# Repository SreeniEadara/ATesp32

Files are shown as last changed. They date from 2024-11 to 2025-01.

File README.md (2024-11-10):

# ATesp32

This is an ATmega32A replacement that uses the ESP32-S3.
Why? Because I bought ATmega32-based keyboard PCBs (the Discipline), love it and want to add wireless capabilities (BLE) and native USB.

I've made efforts to maintain the same number of GPIO, but there will be many differences you would encounter if trying to use this as an ATmega32A replacement. These would include logic levels, availability of analog pins, clock, etc.

Thank you to Adafruit for making the Feather and QtPy boards for the ESP32-S3!
I heavily referenced these in this design.
https://github.com/adafruit/Adafruit-Feather-ESP32-S3-PCB
https://github.com/adafruit/Adafruit-QT-Py-ESP32-S3-PCB/tree/main

Call me an Adafruit shill if you will, but you can support open hardware by purchasing from them.

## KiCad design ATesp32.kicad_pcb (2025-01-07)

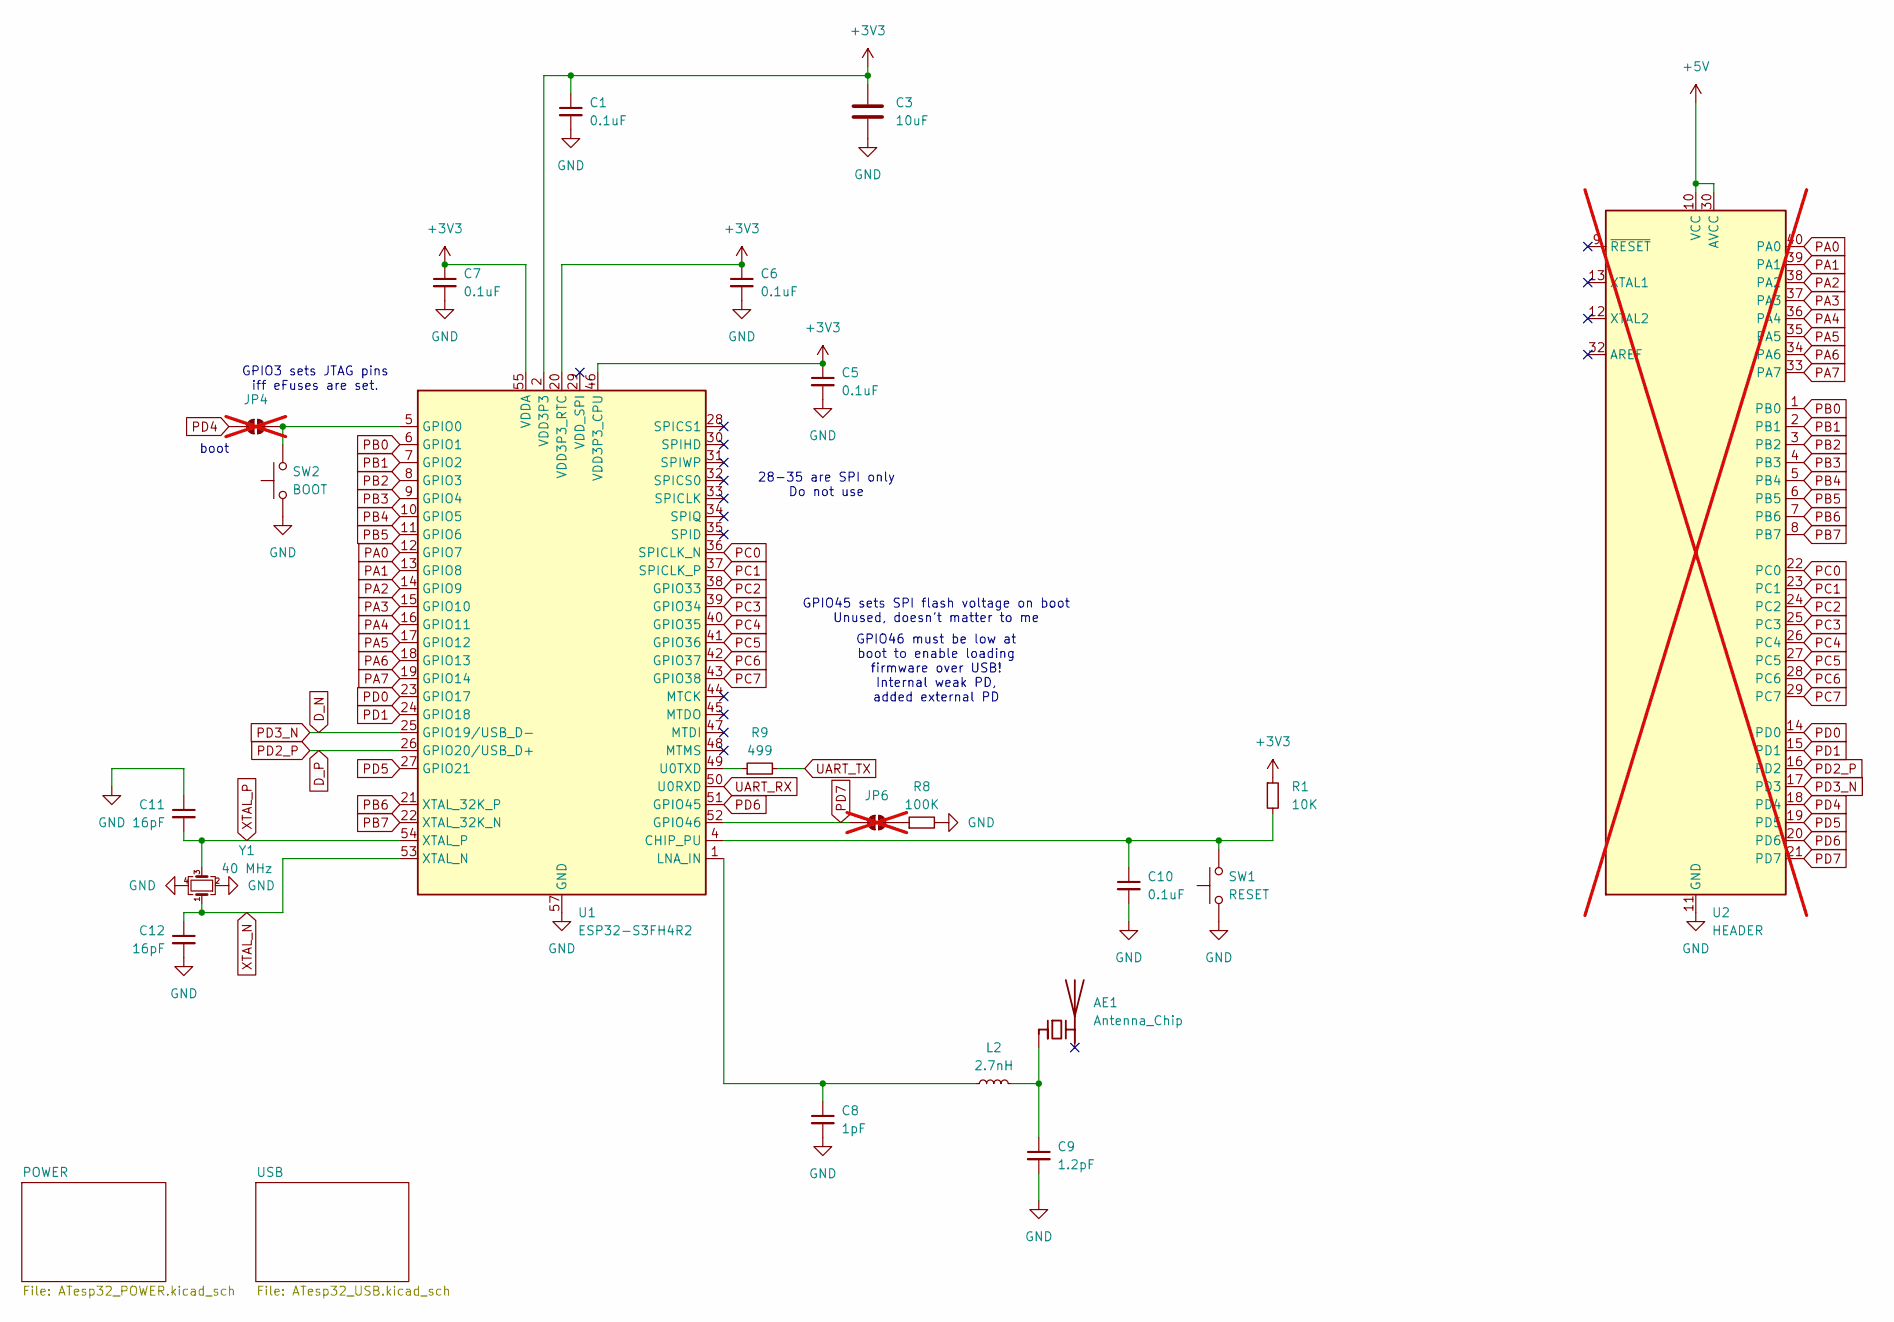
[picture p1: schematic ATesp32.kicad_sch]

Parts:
AE1: Antenna_Chip; Johanson_2450AT18x100; DigiKey 712-2450AT18B0100001ECT-ND
C1, C5, C6, C7, C10: 0.1uF; C_0402_1005Metric; LCSC C1525
C3: 10uF; C_0402_1005Metric; LCSC C315248
C8: 1pF; C_0402_1005Metric; DigiKey 1276-6609-1-ND
C9: 1.2pF; C_0402_1005Metric; DigiKey 1276-1654-1-ND
C11, C12: 16pF; C_0402_1005Metric; LCSC C541434
JP4, JP6: SolderJumper_2_Open; SolderJumper-2_P1.3mm_Open_RoundedPad1.0x1.5mm; not fitted
L2: 2.7nH; L_0402_1005Metric; LCSC C434826
R1: 10K; R_0402_1005Metric; LCSC C25744
R8: 100K; R_0402_1005Metric; LCSC C25741
R9: 499; R_0402_1005Metric; LCSC C4125
SW1: RESET; SW_Push_1P1T_NO_CK_KMR2; LCSC C221680
SW2: BOOT; SW_Push_1P1T_NO_CK_KMR2; LCSC C221680
U1: ESP32-S3FH4R2; QFN-56-1EP_7x7mm_P0.4mm_EP4x4mm; Mouser 356-ESP32-S3FH4R2
U2: HEADER; DIP-40_W15.24mm; not fitted
Y1: 40 MHz; Crystal_SMD_Abracon_ABM8G-4Pin_3.2x2.5mm; DigiKey 535-14086-1-ND

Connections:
+3V3: C1.1, C3.1, C5.1, C6.1, C7.1, R1.1, U1.2 (VDD3P3), U1.3 (VDD3P3), U1.20 (VDD3P3_RTC), U1.46 (VDD3P3_CPU), U1.55 (VDDA), U1.56 (VDDA); also elsewhere on the board
+5V: U2.10 (VCC), U2.30 (AVCC); also elsewhere on the board
D_N: U1.25 (GPIO19/USB_D-), U2.17 (PD3)
D_P: U1.26 (GPIO20/USB_D+), U2.16 (PD2)
GND: C1.2, C3.2, C5.2, C6.2, C7.2, C8.2, C9.2, C10.2, C11.1, C12.2, R8.2, SW1.1, SW2.1, U1.57 (GND), U2.11 (GND), U2.31 (GND), Y1.2, Y1.4; also elsewhere on the board
unnamed: AE1.1 (FEED), C9.1, L2.2
unnamed: JP4.2 (B), SW2.2, U1.5 (GPIO0)
unnamed: JP6.2 (B), R8.1
unnamed: C10.1, R1.2, SW1.2, U1.4 (CHIP_PU)
unnamed: C8.1, L2.1, U1.1 (LNA_IN)
unnamed: R9.1, U1.49 (U0TXD)
PA0: U1.12 (GPIO7), U2.40 (PA0)
PA1: U1.13 (GPIO8), U2.39 (PA1)
PA2: U1.14 (GPIO9), U2.38 (PA2)
PA3: U1.15 (GPIO10), U2.37 (PA3)
PA4: U1.16 (GPIO11), U2.36 (PA4)
PA5: U1.17 (GPIO12), U2.35 (PA5)
PA6: U1.18 (GPIO13), U2.34 (PA6)
PA7: U1.19 (GPIO14), U2.33 (PA7)
PB0: U1.6 (GPIO1), U2.1 (PB0)
PB1: U1.7 (GPIO2), U2.2 (PB1)
PB2: U1.8 (GPIO3), U2.3 (PB2)
PB3: U1.9 (GPIO4), U2.4 (PB3)
PB4: U1.10 (GPIO5), U2.5 (PB4)
PB5: U1.11 (GPIO6), U2.6 (PB5)
PB6: U1.21 (XTAL_32K_P), U2.7 (PB6)
PB7: U1.22 (XTAL_32K_N), U2.8 (PB7)
PC0: U1.36 (SPICLK_N), U2.22 (PC0)
PC1: U1.37 (SPICLK_P), U2.23 (PC1)
PC2: U1.38 (GPIO33), U2.24 (PC2)
PC3: U1.39 (GPIO34), U2.25 (PC3)
PC4: U1.40 (GPIO35), U2.26 (PC4)
PC5: U1.41 (GPIO36), U2.27 (PC5)
PC6: U1.42 (GPIO37), U2.28 (PC6)
PC7: U1.43 (GPIO38), U2.29 (PC7)
PD0: U1.23 (GPIO17), U2.14 (PD0)
PD1: U1.24 (GPIO18), U2.15 (PD1)
PD4: JP4.1 (A), U2.18 (PD4)
PD5: U1.27 (GPIO21), U2.19 (PD5)
PD6: U1.51 (GPIO45), U2.20 (PD6)
PD7: JP6.1 (A), U1.52 (GPIO46), U2.21 (PD7)
UART_RX: U1.50 (U0RXD); also elsewhere on the board
UART_TX: R9.2; also elsewhere on the board
XTAL_N: C12.1, U1.53 (XTAL_N), Y1.1
XTAL_P: C11.2, U1.54 (XTAL_P), Y1.3

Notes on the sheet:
GPIO45 sets SPI flash voltage on boot Unused, doesn't matter to me
boot
28-35 are SPI only Do not use
GPIO3 sets JTAG pins iff eFuses are set.
GPIO46 must be low at boot to enable loading firmware over USB! Internal weak PD, added external PD

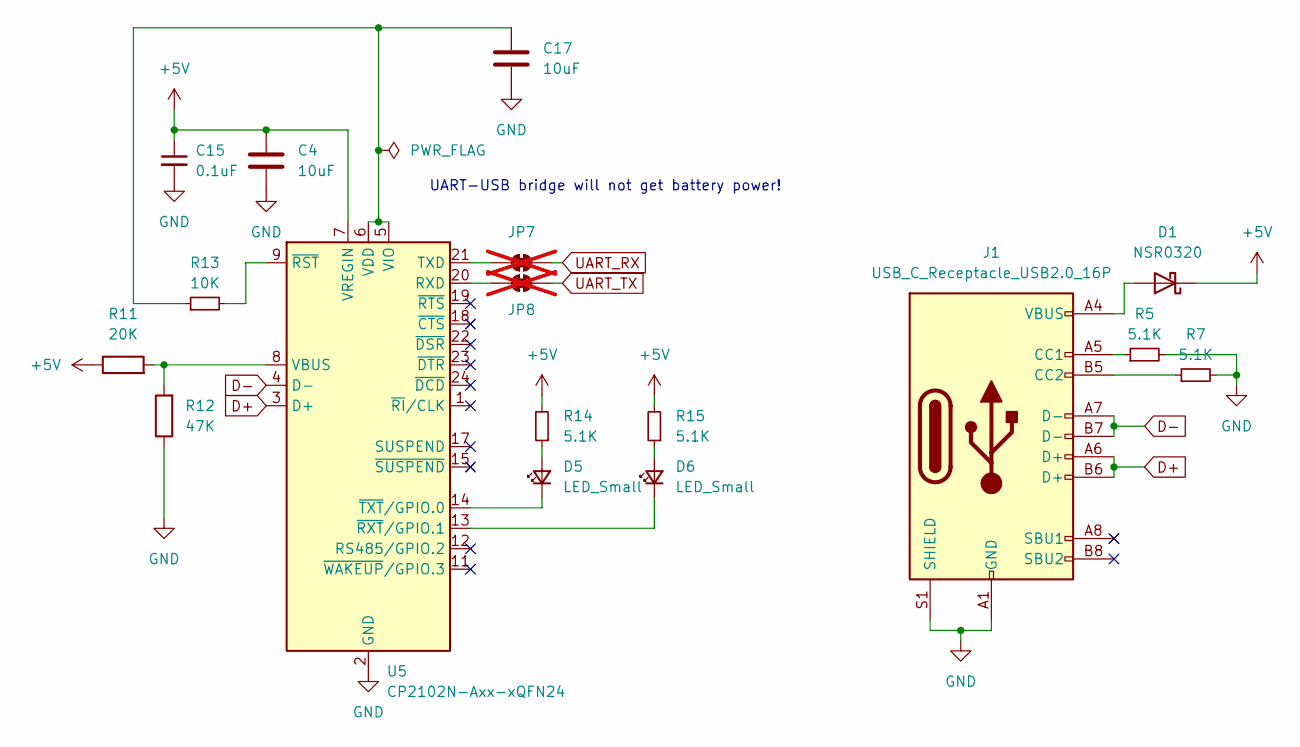
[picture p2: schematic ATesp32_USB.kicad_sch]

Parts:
C4, C17: 10uF; C_0402_1005Metric; LCSC C315248
C15: 0.1uF; C_0402_1005Metric; LCSC C1525
D1: NSR0320; D_SOD-323; LCSC C48192
D5, D6: LED_Small; LED_0402_1005Metric; LCSC C510300
J1: USB_C_Receptacle_USB2.0_16P; USB_C_Receptacle_GCT_USB4105-xx-A_16P_TopMnt_Horizontal; LCSC C2988369
JP7, JP8: SolderJumper_2_Bridged; SolderJumper-2_P1.3mm_Bridged_RoundedPad1.0x1.5mm; not fitted
R5, R7, R14, R15: 5.1K; R_0402_1005Metric; LCSC C25905
R11: 20K; R_0402_1005Metric; LCSC C25765
R12: 47K; R_0402_1005Metric; LCSC C25792
R13: 10K; R_0402_1005Metric; LCSC C25744
U5: CP2102N-Axx-xQFN24; QFN-24-1EP_4x4mm_P0.5mm_EP2.6x2.6mm; LCSC C969151

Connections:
+5V: C4.1, C15.1, D1.1 (K), R11.1, R14.2, R15.2, U5.7 (VREGIN); also elsewhere on the board
D+: J1.A6 (D+), J1.B6 (D+), U5.3 (D+)
D-: J1.A7 (D-), J1.B7 (D-), U5.4 (D-)
GND: C4.2, C15.2, C17.2, J1.A1 (GND), J1.A12 (GND), J1.B1 (GND), J1.B12 (GND), J1.S1 (SHIELD), R5.2, R7.2, R12.1, U5.2 (GND), U5.25 (GND); also elsewhere on the board
unnamed: D1.2 (A), J1.A4 (VBUS), J1.A9 (VBUS), J1.B4 (VBUS), J1.B9 (VBUS)
unnamed: D5.2 (A), R14.1
unnamed: D5.1 (K), U5.14 (~TXT/GPIO.0)
unnamed: D6.2 (A), R15.1
unnamed: D6.1 (K), U5.13 (~RXT/GPIO.1)
unnamed: J1.A5 (CC1), R5.1
unnamed: J1.B5 (CC2), R7.1
unnamed: JP7.1 (A), U5.21 (TXD)
unnamed: JP8.1 (A), U5.20 (RXD)
unnamed: R11.2, R12.2, U5.8 (VBUS)
unnamed: C17.1, R13.1, U5.5 (VIO), U5.6 (VDD)
unnamed: R13.2, U5.9 (~RST)
UART_RX: JP7.2 (B); also elsewhere on the board
UART_TX: JP8.2 (B); also elsewhere on the board

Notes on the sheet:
UART-USB bridge will not get battery power!

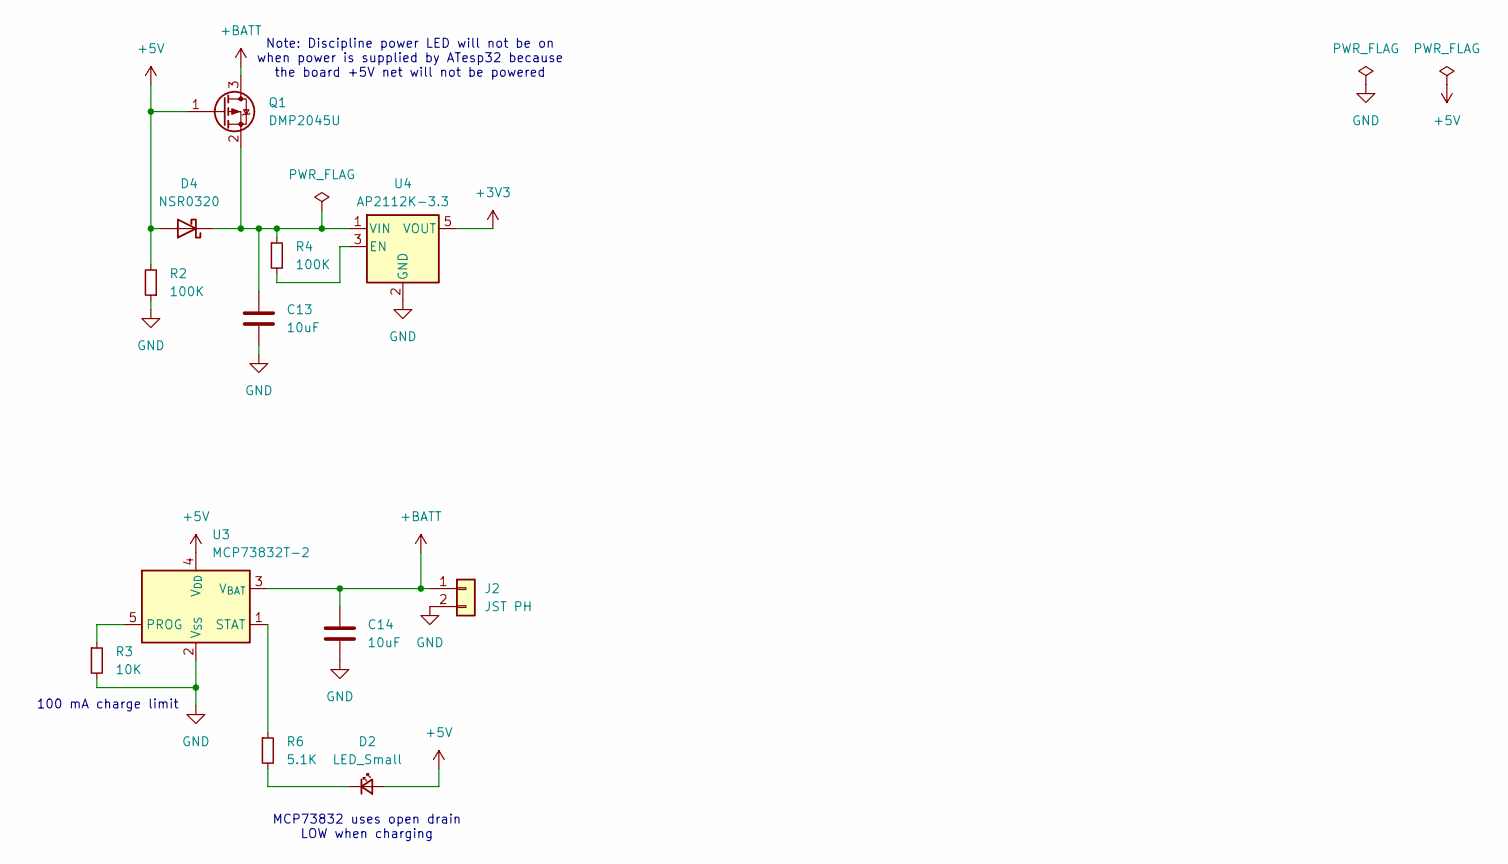
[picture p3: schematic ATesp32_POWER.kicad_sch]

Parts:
C13, C14: 10uF; C_0402_1005Metric; LCSC C315248
D2: LED_Small; LED_0402_1005Metric; LCSC C510300
D4: NSR0320; D_SOD-323; LCSC C48192
J2: JST PH; JST_PH_S2B-PH-SM4-TB_1x02-1MP_P2.00mm_Horizontal; LCSC C295747
Q1: DMP2045U; SOT-23; LCSC C459541
R2, R4: 100K; R_0402_1005Metric; LCSC C25741
R3: 10K; R_0402_1005Metric; LCSC C25744
R6: 5.1K; R_0402_1005Metric; LCSC C25905
U3: MCP73832T-2; SOT-23-5; LCSC C38066
U4: AP2112K-3.3; SOT-23-5; LCSC C51118

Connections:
+3V3: U4.5 (VOUT); also elsewhere on the board
+5V: D2.2 (A), D4.2 (A), Q1.1 (G), R2.2, U3.4 (V_{DD}); also elsewhere on the board
+BATT: C14.1, J2.1, Q1.3 (D), U3.3 (V_{BAT})
GND: C13.2, C14.2, J2.2, R2.1, R3.2, U3.2 (V_{SS}), U4.2 (GND); also elsewhere on the board
unnamed: D2.1 (K), R6.2
unnamed: C13.1, D4.1 (K), Q1.2 (S), R4.1, U4.1 (VIN)
unnamed: R3.1, U3.5 (PROG)
unnamed: R6.1, U3.1 (STAT)
unnamed: R4.2, U4.3 (EN)

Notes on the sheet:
100 mA charge limit
Note: Discipline power LED will not be on when power is supplied by ATesp32 because the board +5V net will not be powered
MCP73832 uses open drain LOW when charging

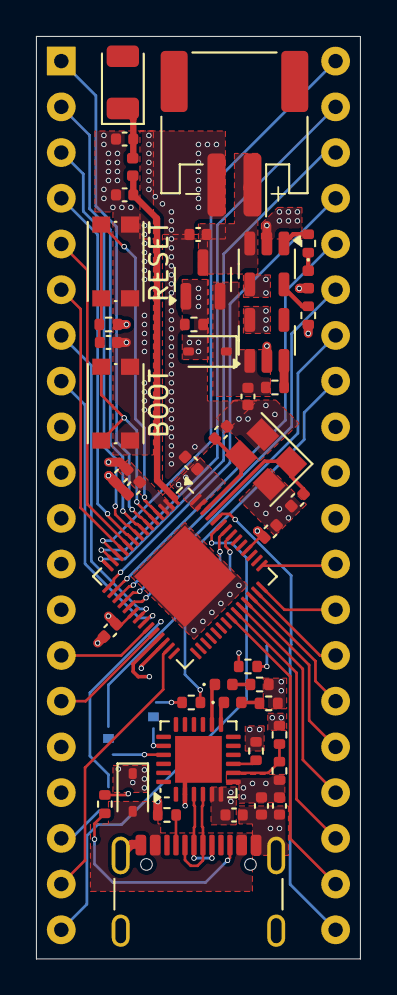
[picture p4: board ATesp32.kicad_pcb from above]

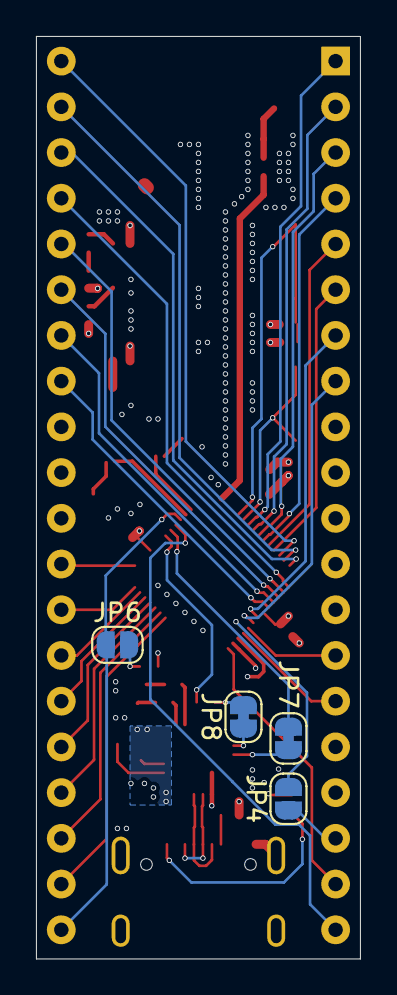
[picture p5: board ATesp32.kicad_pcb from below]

Board: 4 copper layers, 18.0 x 51.2 mm, 51 parts (4 on the bottom side), 65 nets.

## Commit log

2024-11-10 Adding ATesp32 schematic. In development
    [ATesp32.kicad_pcb, ATesp32.kicad_sch, ATesp32_POWER.kicad_sch]
2024-11-10 Added USB-UART bridge for programming
    [ATesp32.kicad_sch, ATesp32_POWER.kicad_sch, ATesp32_USB.kicad_sch]
2024-11-10 first pass at footprint assignment
    [ATesp32.kicad_pcb, ATesp32.kicad_sch, ATesp32_POWER.kicad_sch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]
2024-11-10 remove misc superfluous components
    [ATesp32.kicad_pcb, ATesp32.kicad_sch, ATesp32_POWER.kicad_sch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]
2024-11-11 first pass at component placement
    [ATesp32.kicad_pcb, ATesp32.kicad_sch, ATesp32_POWER.kicad_sch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]
2024-11-11 centered headers and USB-C. Set grid and drill origins
    [ATesp32.kicad_pcb]
2024-11-12 Finished layout, need to fix silk
    [ATesp32.kicad_pcb, ATesp32.kicad_sch]
2024-11-12 fix USB routing
    [ATesp32.kicad_pcb]
2024-11-13 fix pours
    [ATesp32.kicad_pcb]
2024-11-14 Better fencing near antenna trace
    [ATesp32.kicad_pcb]
2024-11-14 adjust 3v3 pour
    [ATesp32.kicad_pcb]
2024-11-16 fix silk
    [ATesp32.kicad_pcb, ATesp32.kicad_sch]
2024-11-16 move crystal farther from chip
    [ATesp32.kicad_pcb, ATesp32.kicad_sch]
2024-11-16 critical error - changed to correct mosfet pin numbers
    [ATesp32.kicad_pcb, ATesp32_POWER.kicad_sch]
2024-11-16 satisfy DRC and ERC
    [ATesp32.kicad_pcb, ATesp32.kicad_sch, ATesp32_USB.kicad_sch]
2024-11-16 antenna was backwards
    [ATesp32.kicad_pcb, ATesp32.kicad_sch]
2024-11-16 small layout optimization
    [ATesp32.kicad_pcb]
2024-11-16 fix bug - correct use of open drain status signal of lipo charger
    [ATesp32.kicad_pcb, ATesp32_POWER.kicad_sch]
2024-11-16 spec components for JLC
    [ATesp32.kicad_pcb, ATesp32.kicad_sch, ATesp32_POWER.kicad_sch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]
2024-11-16 Generate production files. More clear part names for ESP and LiPo charger
    [ATesp32-B_Cu.gbr, ATesp32-B_Mask.gbr, ATesp32-B_Paste.gbr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]
2024-11-17 generated manf files. Too damn expensive, adjusting min track and holes
    [ATesp32-B_Cu.gbr, ATesp32-B_Mask.gbr, ATesp32-B_Paste.gbr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]
2024-11-24 Add some Mouser PNs
    [ATesp32.kicad_pcb, ATesp32.kicad_sch, ATesp32_POWER.kicad_sch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]
2024-11-24 update manf outputs
    [ATesp32-B_Cu.gbr, ATesp32-B_Mask.gbr, ATesp32-B_Paste.gbr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]
2024-12-09 USB-UART Bridge LEDs had wrong orientation. Fixed
    [ATesp32-B_Cu.gbr, ATesp32-B_Mask.gbr, ATesp32-B_Paste.gbr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]
2025-01-07 LEDs were persistently on. Change to active low config see CP2102N datasheet fig 4.3
    [ATesp32.kicad_pcb, ATesp32_USB.kicad_sch]
